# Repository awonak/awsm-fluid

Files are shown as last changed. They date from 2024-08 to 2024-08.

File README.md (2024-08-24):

# AWSM - Fluid

> [!NOTE]  
> This project is a work in progress and may contain errors.

3u 12hp Arduino based multi-purpose utility module. 

## Features

**Digital Inputs**

* 2 digital gate/trig inputs
* 2 buttons

**Analog Inputs**

* 4 slide potentiometers w/ addressable LEDs
* 4 CV inputs (-5v to 5v) w/ attenuator pots, summed with each slide pot.

**Analog Outputs**

* 2 PWM 0-10v outputs w/ LED indicator
* Each output paired with additional output which can be an inverted copy (-10v to 0v) or bipolar output (-10v to 10v).

## Concept

This module is meant to be a platform for creating unique utility module scripts using the given inputs and outputs. Some firmware examples are:

* CV controlable ADSR with gate / retrig inputs, envelope curves selected via button, envelope output with EOR/EOF output trigger.
* Clocked burst generator with high gate output during burst sequence.
* Dual LFO w/ shape and rate.
* Random cv generator w/ envelopes.

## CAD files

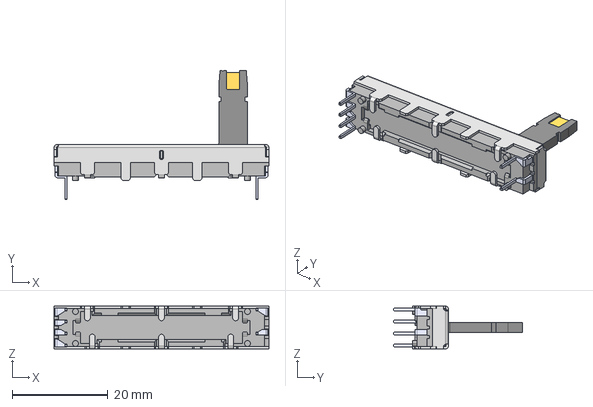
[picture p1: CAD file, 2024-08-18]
models/PTL20-15R0-103B1.step
45.0 x 27.0 x 9.00 mm

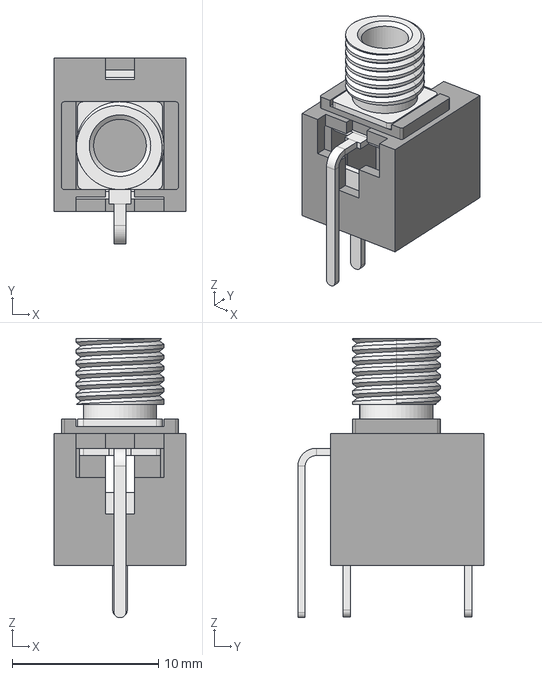
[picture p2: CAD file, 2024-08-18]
models/PJ398SM.step
9.00 x 12.7 x 19.1 mm

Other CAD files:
models/PTL30-15W1-103B1.step

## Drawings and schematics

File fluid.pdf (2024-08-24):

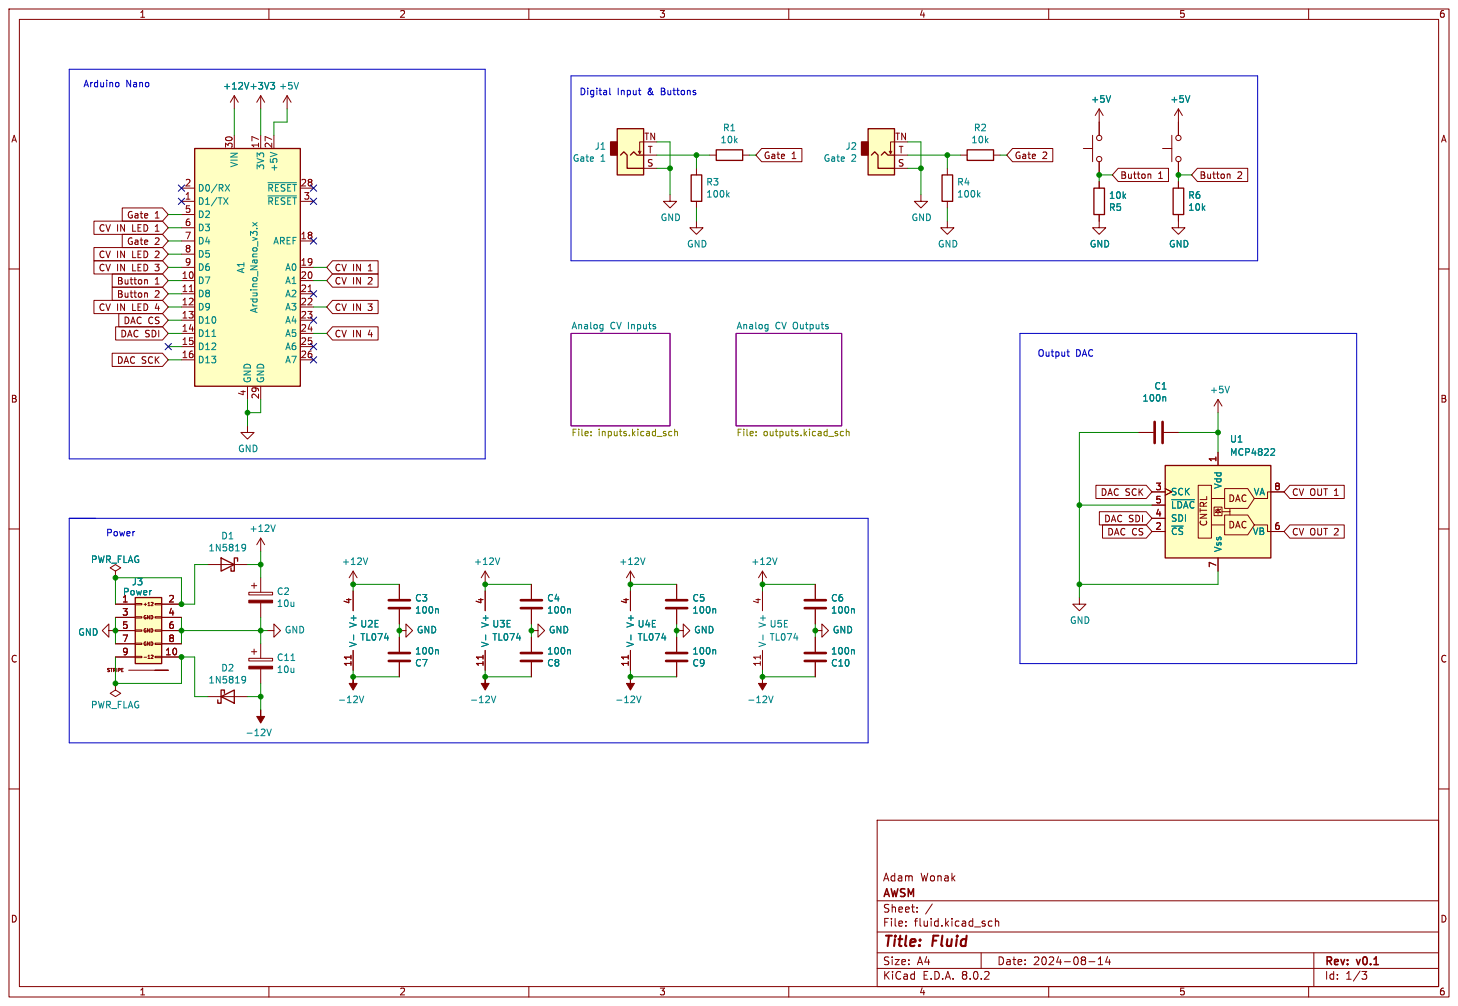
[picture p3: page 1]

1 ~{CS} 2 SCK 3 SDI 4 ~{LDAC} 5 VB 6 Vss 7 VA 8 GND

Analog CV Outputs File: outputs.kicad_sch GND

Analog CV Inputs File: inputs.kicad_sch

1 ~{CS} 2 SCK 3 SDI 4 ~{LDAC} 5 VB 6 Vss 7 VA 8 U1 MCP4822 C2

Adam Wonak
File: fluid.kicad_sch Sheet: / AWSM

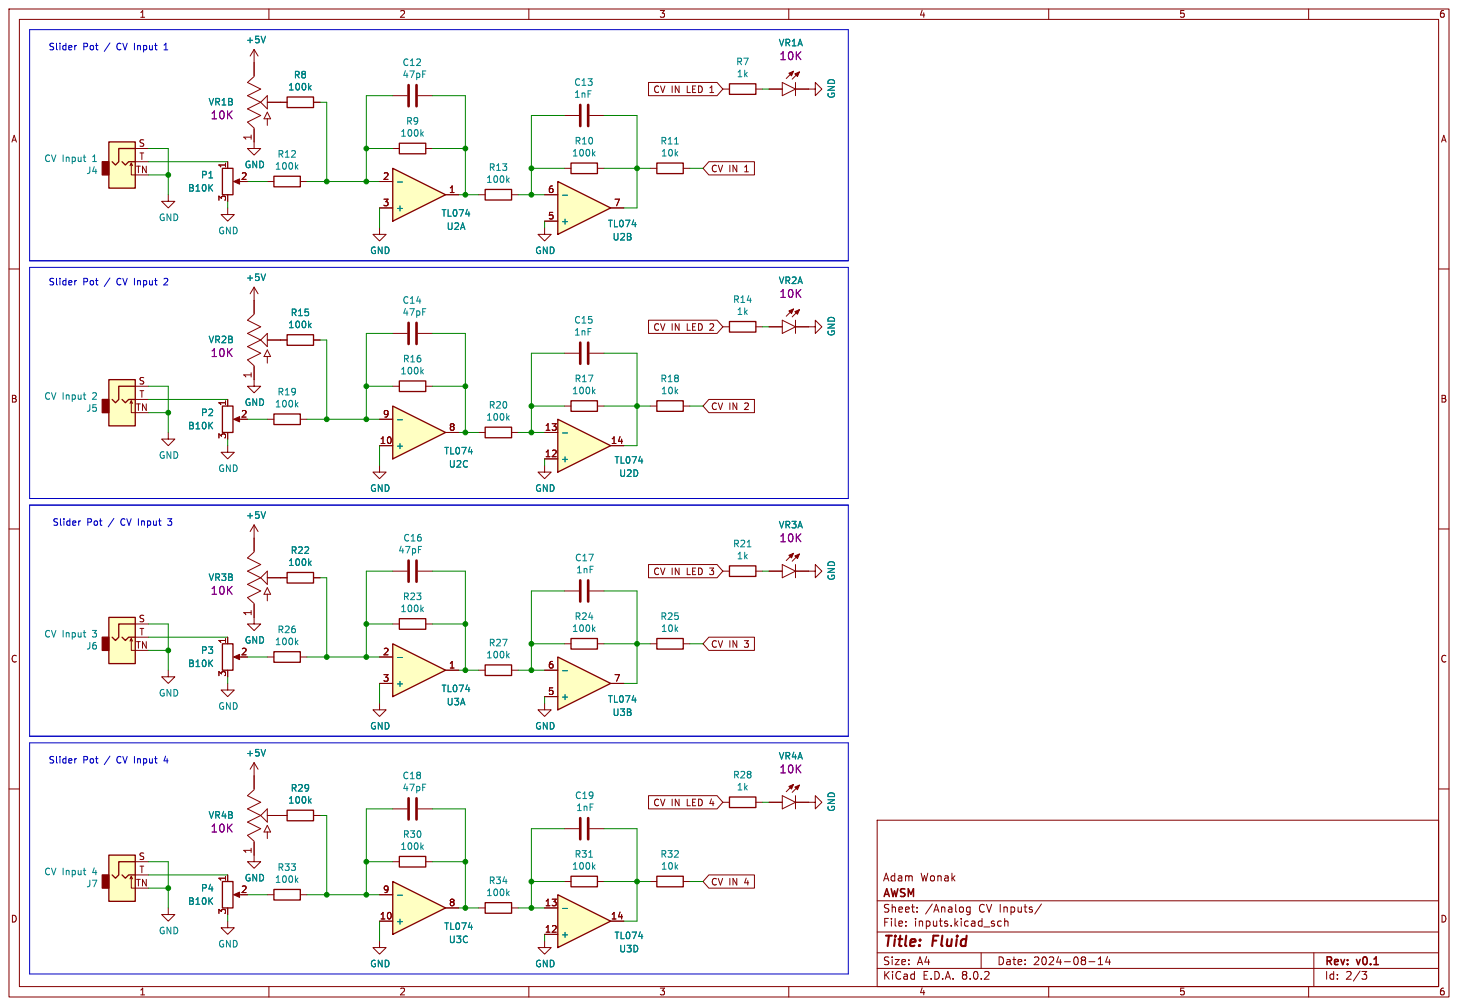
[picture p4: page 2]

CV IN LED 1 CV IN LED 3CV IN 3 CV IN LED 2CV IN 2 CV IN 1
TL074 GND GND ST

CV IN 4 CV IN LED 4 Slider Pot / CV Input 4

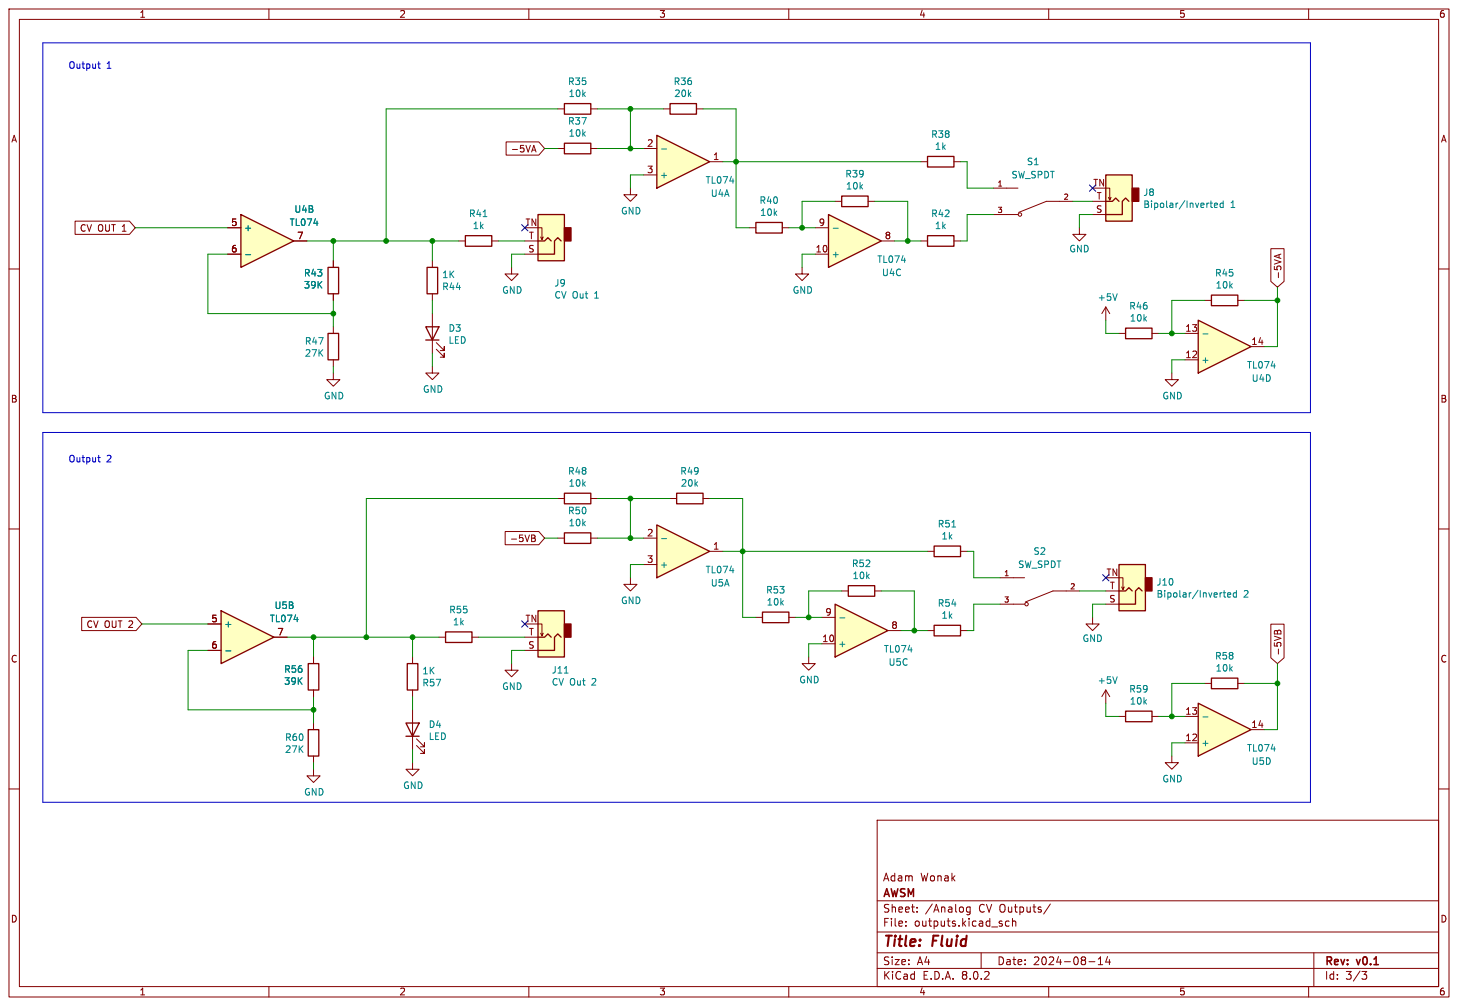
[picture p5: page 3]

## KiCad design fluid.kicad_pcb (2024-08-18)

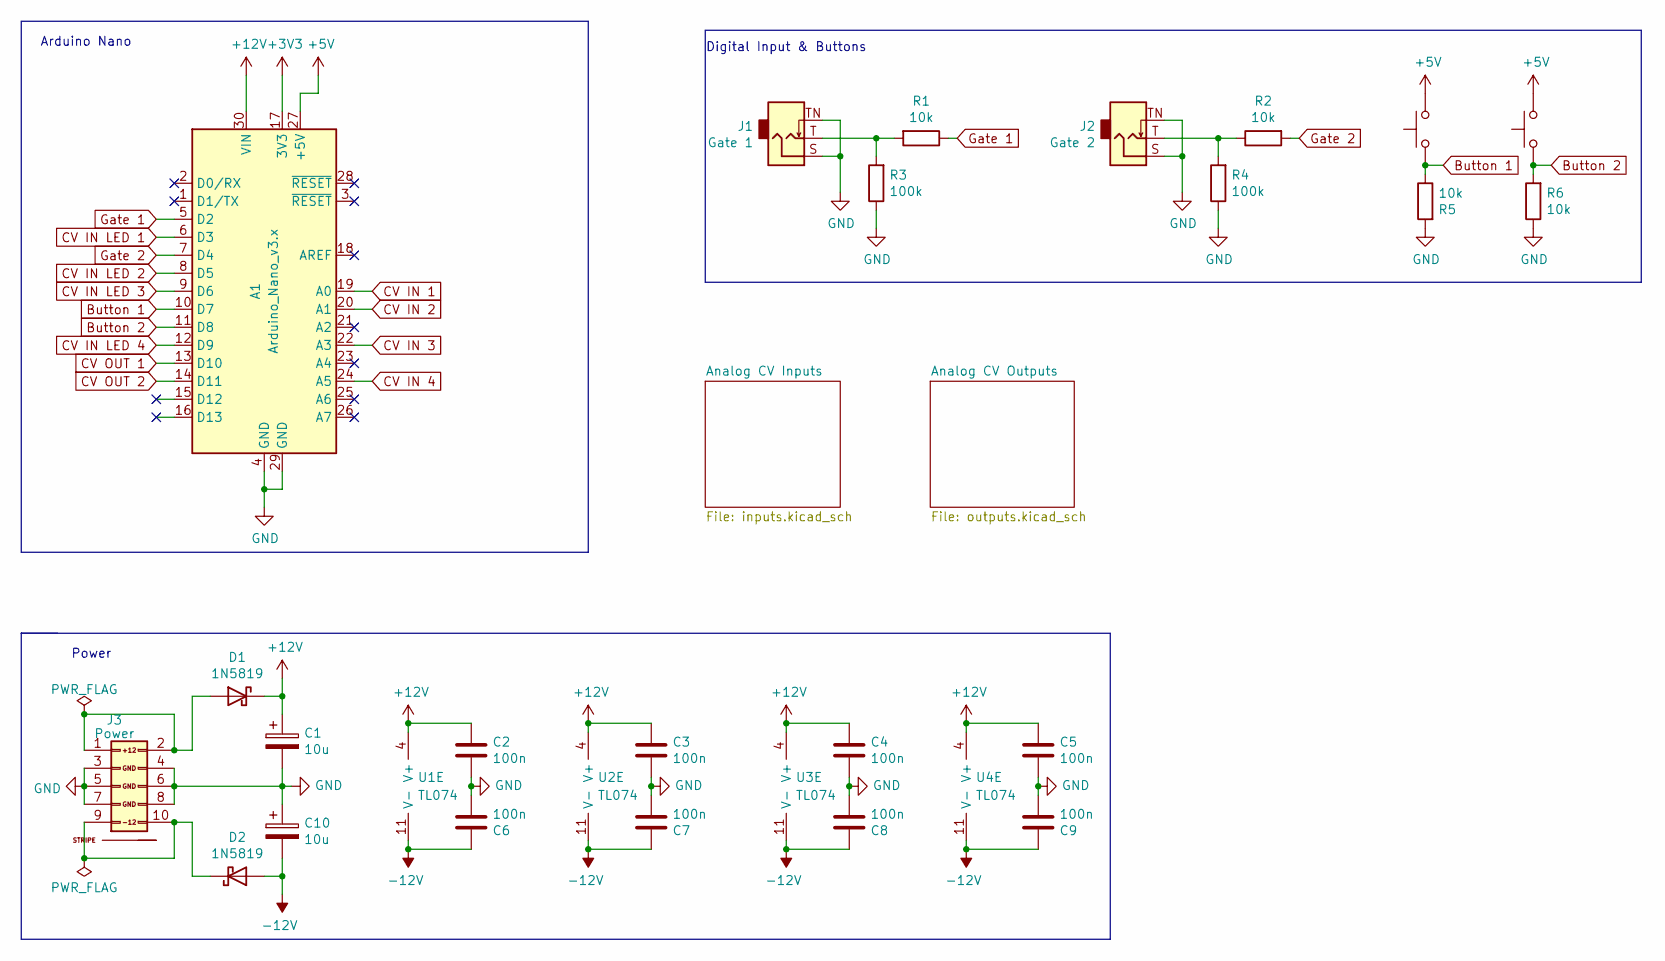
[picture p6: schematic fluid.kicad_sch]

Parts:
A1: Arduino_Nano_v3.x; Arduino_Nano
C1, C10: 10u; CP_EIA-3216-18_Kemet-A; LCSC C7171
C2, C3, C4, C5, C6, C7, C8, C9: 100n; C_0402_1005Metric; LCSC C1525
D1, D2: 1N5819; D_SOD-323; LCSC C191023
J1: Gate 1; Jack_3.5mm_QingPu_WQP-PJ398SM_Vertical_CircularHoles_3dModel
J2: Gate 2; Jack_3.5mm_QingPu_WQP-PJ398SM_Vertical_CircularHoles_3dModel
J3: Power; Pins_2x05_2.54mm_TH_EurorackPower
R1, R2, R5, R6: 10k; R_0402_1005Metric; LCSC C25744
R3, R4: 100k; R_0402_1005Metric; LCSC C25741
SW1, SW2: Button; SW_PUSH_6mm
U1, U2, U3, U4: TL074; SOIC-14_3.9x8.7mm_P1.27mm; LCSC C6963

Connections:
+3V3: A1.17 (3V3)
+5V: A1.27 (+5V), SW1.2, SW2.2; also elsewhere on the board
+12V: A1.30 (VIN), C1.1, C2.2, C3.2, C4.2, C5.2, D1.1 (K), U1.4 (V+), U2.4 (V+), U3.4 (V+), U4.4 (V+)
-12V: C6.2, C7.2, C8.2, C9.2, C10.2, D2.2 (A), U1.11 (V-), U2.11 (V-), U3.11 (V-), U4.11 (V-)
Button 1: A1.10 (D7), R5.1, SW1.1
Button 2: A1.11 (D8), R6.2, SW2.1
CV IN 1: A1.19 (A0); also elsewhere on the board
CV IN 2: A1.20 (A1); also elsewhere on the board
CV IN 3: A1.22 (A3); also elsewhere on the board
CV IN 4: A1.24 (A5); also elsewhere on the board
CV IN LED 1: A1.6 (D3); also elsewhere on the board
CV IN LED 2: A1.8 (D5); also elsewhere on the board
CV IN LED 3: A1.9 (D6); also elsewhere on the board
CV IN LED 4: A1.12 (D9); also elsewhere on the board
CV OUT 1: A1.13 (D10); also elsewhere on the board
CV OUT 2: A1.14 (D11); also elsewhere on the board
GND: A1.4 (GND), A1.29 (GND), C1.2, C2.1, C3.1, C4.1, C5.1, C6.1, C7.1, C8.1, C9.1, C10.1, J1.S, J1.TN, J2.S, J2.TN, J3.3 (GND), J3.4 (GND), J3.5 (GND), J3.6 (GND), J3.7 (GND), J3.8 (GND), R3.1, R4.1, R5.2, R6.1; also elsewhere on the board
Gate 1: A1.5 (D2), R1.1
Gate 2: A1.7 (D4), R2.2
unnamed: D1.2 (A), J3.1 (+12V), J3.2 (+12V)
unnamed: D2.1 (K), J3.9 (-12V), J3.10 (-12V)
unnamed: J1.T, R1.2, R3.2
unnamed: J2.T, R2.1, R4.2

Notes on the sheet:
Arduino Nano
Power
Digital Input & Buttons

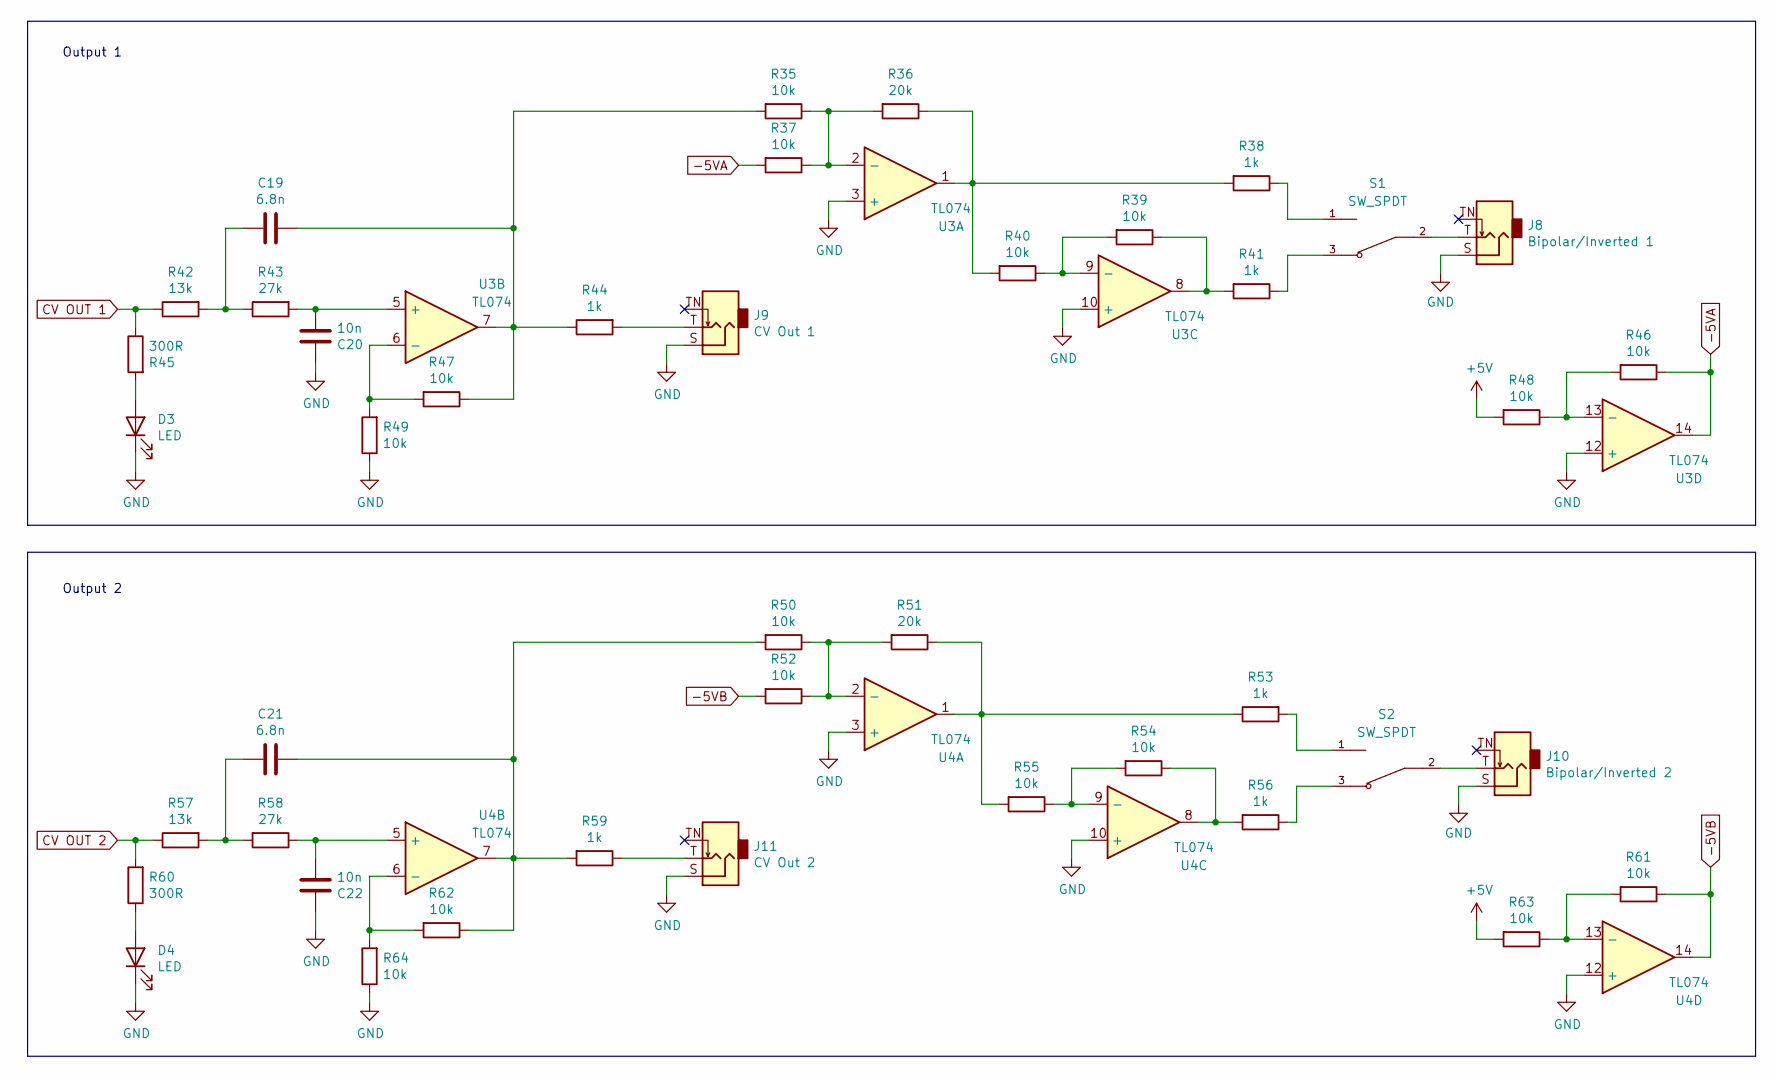
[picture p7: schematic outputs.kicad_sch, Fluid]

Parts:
C19, C21: 6.8n; C_0402_1005Metric; LCSC C1542
C20, C22: 10n; C_0402_1005Metric; LCSC C15195
D3, D4: LED; LED_D3.0mm
J8: Bipolar/Inverted 1; Jack_3.5mm_QingPu_WQP-PJ398SM_Vertical_CircularHoles_3dModel
J9: CV Out 1; Jack_3.5mm_QingPu_WQP-PJ398SM_Vertical_CircularHoles_3dModel
J10: Bipolar/Inverted 2; Jack_3.5mm_QingPu_WQP-PJ398SM_Vertical_CircularHoles_3dModel
J11: CV Out 2; Jack_3.5mm_QingPu_WQP-PJ398SM_Vertical_CircularHoles_3dModel
R35, R37, R39, R40, R46, R47, R48, R49, R50, R52, R54, R55, R61, R62, R63, R64: 10k; R_0402_1005Metric; LCSC C25744
R36, R51: 20k; R_0402_1005Metric; LCSC C25765
R38, R41, R44, R53, R56, R59: 1k; R_0402_1005Metric; LCSC C11702
R42, R57: 13k; R_0603_1608Metric; LCSC C22797
R43, R58: 27k; R_0402_1005Metric; LCSC C25771
R45, R60: 300R; R_0402_1005Metric; LCSC C25102
S1, S2: SW_SPDT; SW_2MS1T1B1M2QES
U3, U4: TL074; SOIC-14_3.9x8.7mm_P1.27mm; LCSC C6963

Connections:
+5V: R48.2, R63.2; also elsewhere on the board
-5VA: R37.2, R46.1, U3.14
-5VB: R52.2, R61.1, U4.14
CV OUT 1: R42.1, R45.1; also elsewhere on the board
CV OUT 2: R57.1, R60.2; also elsewhere on the board
GND: C20.2, C22.2, D3.1 (K), D4.1 (K), J8.S, J9.S, J10.S, J11.S, R49.1, R64.1, U3.3 (+), U3.10 (+), U3.12 (+), U4.3 (+), U4.10 (+), U4.12 (+); also elsewhere on the board
unnamed: C19.1, R35.2, R44.1, R47.1, U3.7
unnamed: C19.2, R42.2, R43.1
unnamed: C21.1, R50.2, R59.2, R62.1, U4.7
unnamed: C21.2, R57.2, R58.2
unnamed: D3.2 (A), R45.2
unnamed: D4.2 (A), R60.1
unnamed: J8.T, S1.2
unnamed: J9.T, R44.2
unnamed: J10.T, S2.2
unnamed: J11.T, R59.1
unnamed: R36.1, R38.2, R40.2, U3.1
unnamed: R38.1, S1.1
unnamed: R39.1, R41.2, U3.8
unnamed: R41.1, S1.3
unnamed: R51.1, R53.1, R55.2, U4.1
unnamed: R53.2, S2.1
unnamed: R54.1, R56.2, U4.8
unnamed: R56.1, S2.3
unnamed: R35.1, R36.2, R37.1, U3.2 (-)
unnamed: C20.1, R43.2, U3.5 (+)
unnamed: R47.2, R49.2, U3.6 (-)
unnamed: R39.2, R40.1, U3.9 (-)
unnamed: R46.2, R48.1, U3.13 (-)
unnamed: R50.1, R51.2, R52.1, U4.2 (-)
unnamed: C22.1, R58.1, U4.5 (+)
unnamed: R62.2, R64.2, U4.6 (-)
unnamed: R54.2, R55.1, U4.9 (-)
unnamed: R61.2, R63.1, U4.13 (-)

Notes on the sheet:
Output 2
Output 1

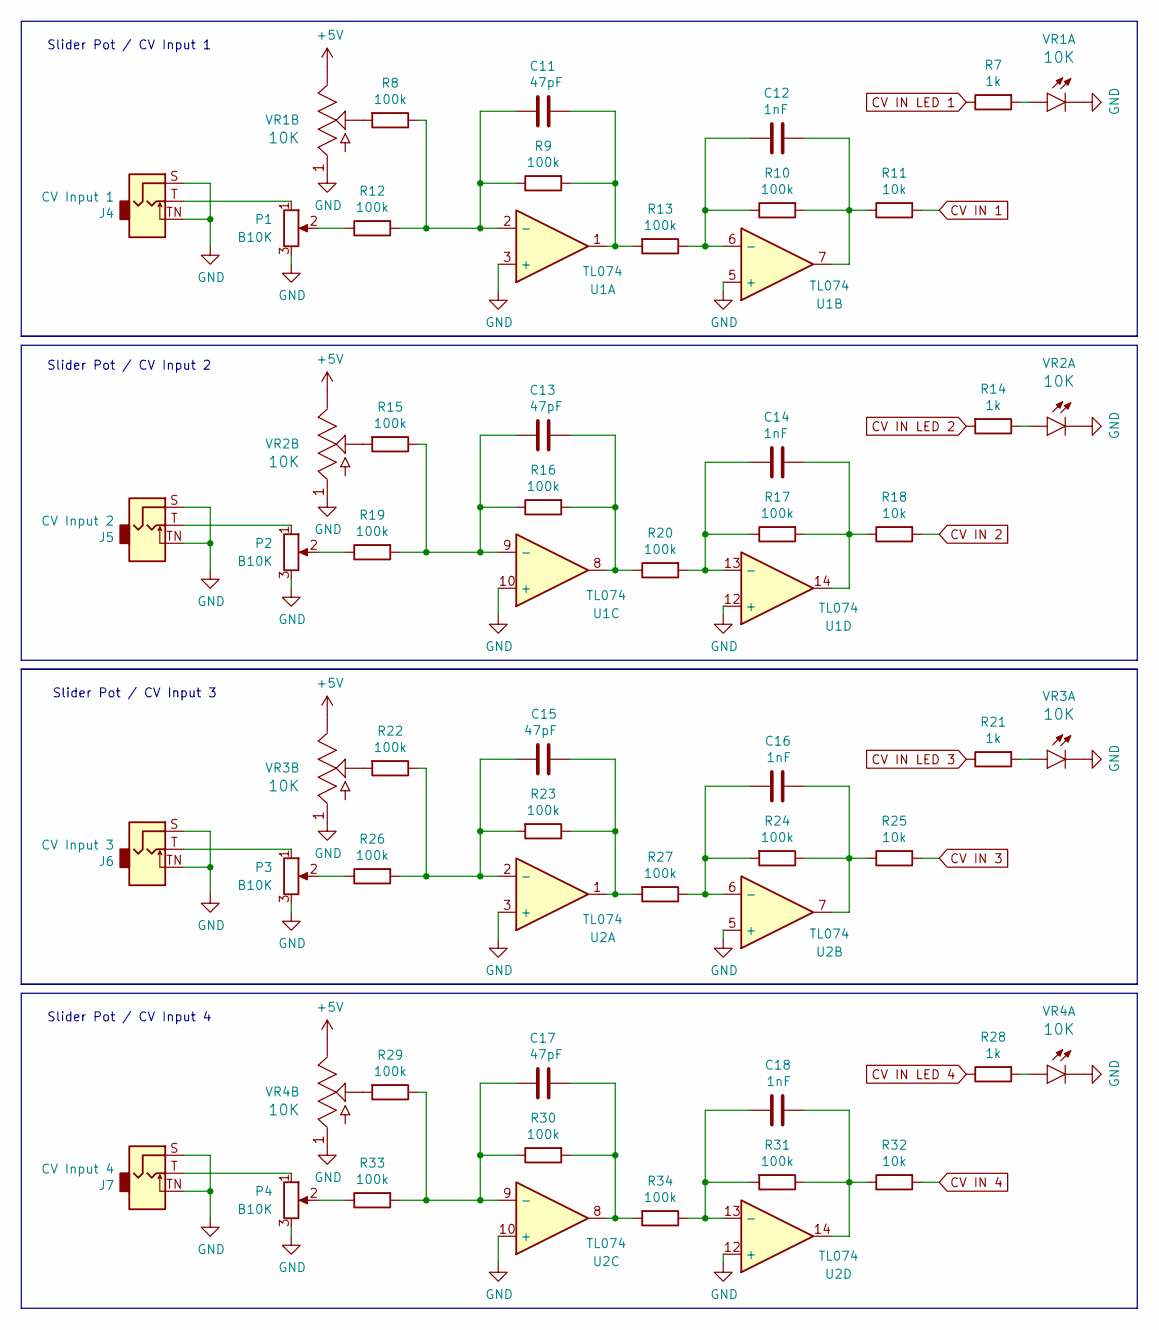
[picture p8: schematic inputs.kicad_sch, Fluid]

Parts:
C11, C13, C15, C17: 47pF; C_0402_1005Metric; LCSC C1567
C12, C14, C16, C18: 1nF; C_0402_1005Metric; LCSC C1523
J4: CV Input 1; Jack_3.5mm_QingPu_WQP-PJ398SM_Vertical_CircularHoles_3dModel
J5: CV Input 2; Jack_3.5mm_QingPu_WQP-PJ398SM_Vertical_CircularHoles_3dModel
J6: CV Input 3; Jack_3.5mm_QingPu_WQP-PJ398SM_Vertical_CircularHoles_3dModel
J7: CV Input 4; Jack_3.5mm_QingPu_WQP-PJ398SM_Vertical_CircularHoles_3dModel
P1, P2, P3, P4: B10K; Potentiometer_Alpha_RD901F-40-00D_Single_Vertical
R7, R14, R21, R28: 1k; R_0402_1005Metric; LCSC C11702
R8, R9, R10, R12, R13, R15, R16, R17, R19, R20, R22, R23, R24, R26, R27, R29, R30, R31, R33, R34: 100k; R_0402_1005Metric; LCSC C25741
R11, R18, R25, R32: 10k; R_0402_1005Metric; LCSC C25744
U1, U2: TL074; SOIC-14_3.9x8.7mm_P1.27mm; LCSC C6963
VR1, VR2, VR3, VR4: 10K; Pot_Slider_LED_20mm_RA2045F

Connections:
+5V: VR1.P3 (3), VR2.P3 (3), VR3.P3 (3), VR4.P3 (3); also elsewhere on the board
CV IN 1: R11.2; also elsewhere on the board
CV IN 2: R18.2; also elsewhere on the board
CV IN 3: R25.2; also elsewhere on the board
CV IN 4: R32.2; also elsewhere on the board
CV IN LED 1: R7.1; also elsewhere on the board
CV IN LED 2: R14.2; also elsewhere on the board
CV IN LED 3: R21.1; also elsewhere on the board
CV IN LED 4: R28.1; also elsewhere on the board
GND: J4.S, J4.TN, J5.S, J5.TN, J6.S, J6.TN, J7.S, J7.TN, P1.3, P2.3, P3.3, P4.3, U1.3 (+), U1.5 (+), U1.10 (+), U1.12 (+), U2.3 (+), U2.5 (+), U2.10 (+), U2.12 (+), VR1.LEDC (C), VR1.P1 (1), VR2.LEDC (C), VR2.P1 (1), VR3.LEDC (C), VR3.P1 (1), VR4.LEDC (C), VR4.P1 (1); also elsewhere on the board
unnamed: C11.1, R9.2, R13.2, U1.1
unnamed: C12.1, R10.2, R11.1, U1.7
unnamed: C13.1, R16.2, R20.1, U1.8
unnamed: C14.1, R17.2, R18.1, U1.14
unnamed: C15.2, R23.1, R27.2, U2.1
unnamed: C16.2, R24.1, R25.1, U2.7
unnamed: C17.1, R30.2, R34.2, U2.8
unnamed: C18.2, R31.1, R32.1, U2.14
unnamed: J4.T, P1.1
unnamed: J5.T, P2.1
unnamed: J6.T, P3.1
unnamed: J7.T, P4.1
unnamed: P1.2, R12.1
unnamed: P2.2, R19.1
unnamed: P3.2, R26.1
unnamed: P4.2, R33.1
unnamed: C11.2, R8.1, R9.1, R12.2, U1.2 (-)
unnamed: C12.2, R10.1, R13.1, U1.6 (-)
unnamed: C13.2, R15.1, R16.1, R19.2, U1.9 (-)
unnamed: C14.2, R17.1, R20.2, U1.13 (-)
unnamed: C15.1, R22.1, R23.2, R26.2, U2.2 (-)
unnamed: C16.1, R24.2, R27.1, U2.6 (-)
unnamed: C17.2, R29.1, R30.1, R33.2, U2.9 (-)
unnamed: C18.1, R31.2, R34.1, U2.13 (-)
unnamed: R7.2, VR1.LEDA (A)
unnamed: R8.2, VR1.P2 (2)
unnamed: R14.1, VR2.LEDA (A)
unnamed: R15.2, VR2.P2 (2)
unnamed: R21.2, VR3.LEDA (A)
unnamed: R22.2, VR3.P2 (2)
unnamed: R28.2, VR4.LEDA (A)
unnamed: R29.2, VR4.P2 (2)

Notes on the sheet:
Slider Pot / CV Input 2
Slider Pot / CV Input 4
Slider Pot / CV Input 1
Slider Pot / CV Input 3

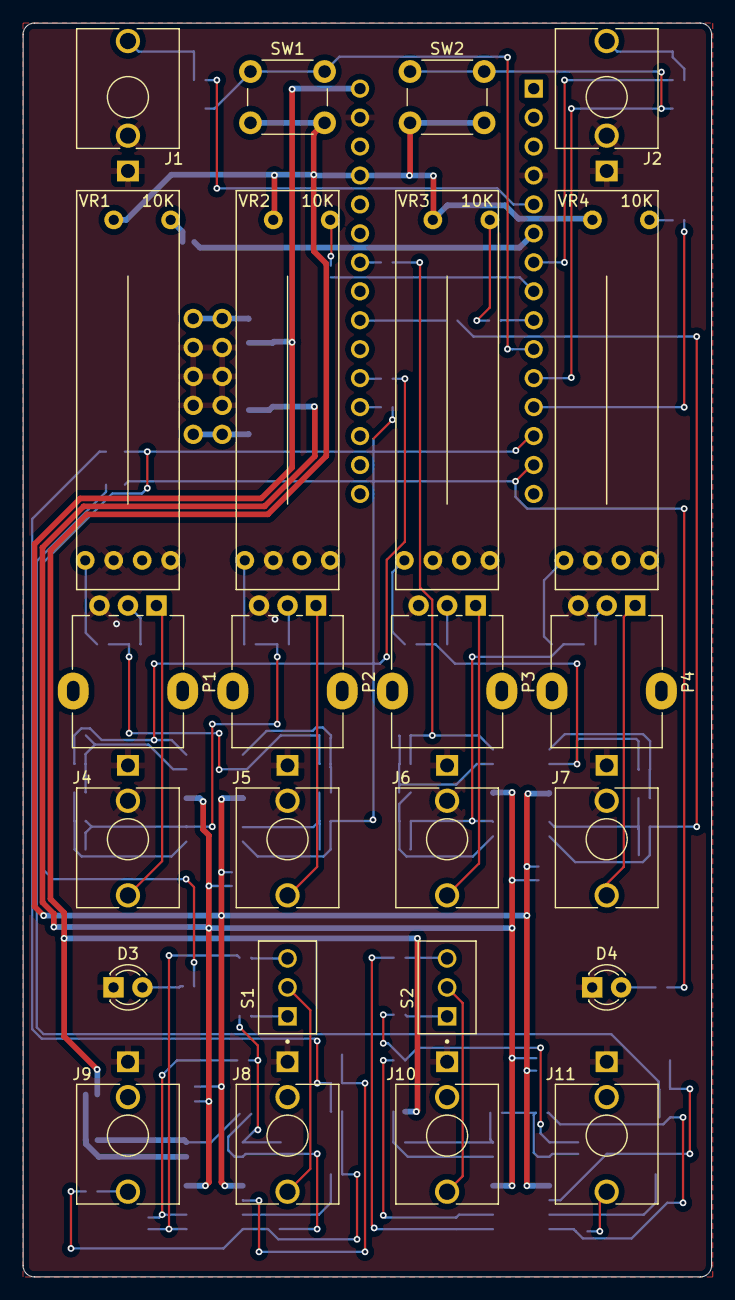
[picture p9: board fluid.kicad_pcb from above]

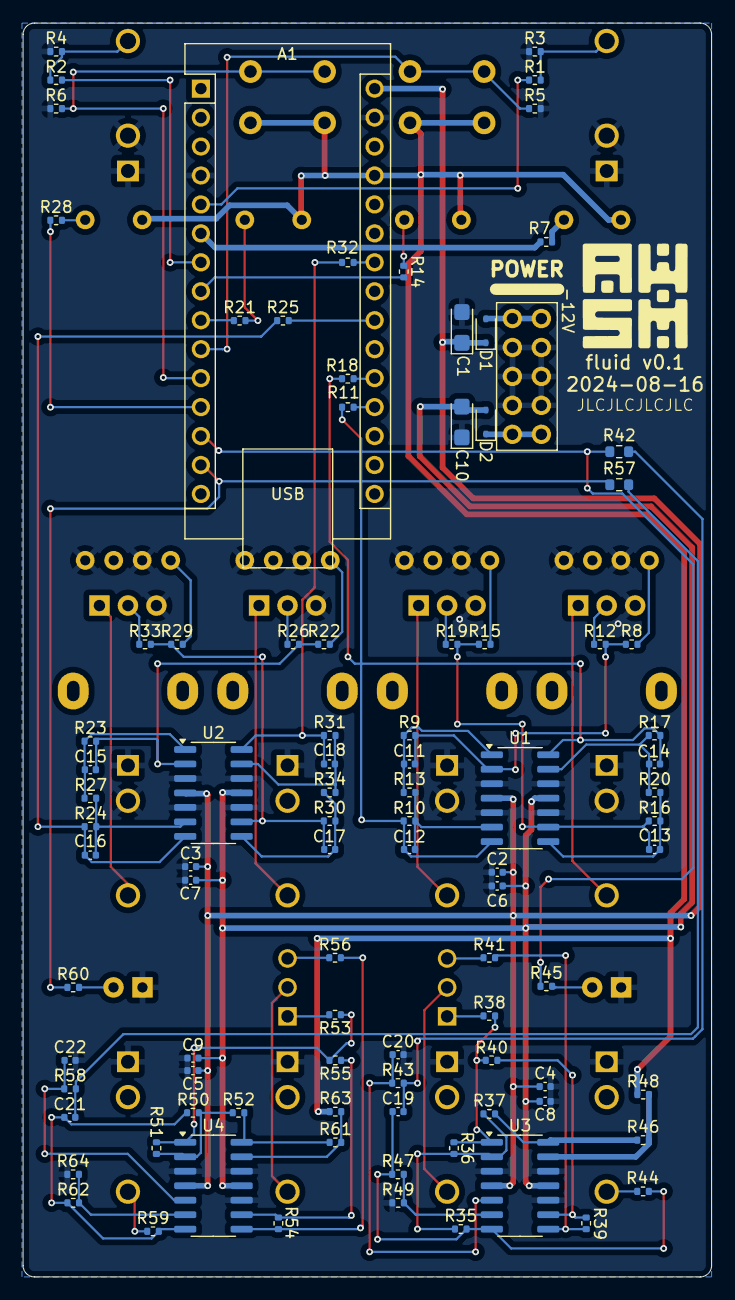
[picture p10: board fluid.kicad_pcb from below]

Board: 2 copper layers, 60.4 x 110.0 mm, 118 parts (94 on the bottom side), 84 nets.

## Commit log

2024-08-18 fixed absolute symbol reference. rounded corners of pcb.
    [fluid.kicad_pcb]
2024-08-24 Reintroduce the DAC with gain boost from 4.096v to 9.99v. Refactor output LED, increase LED resistor value.
    [fluid.kicad_sch, inputs.kicad_sch, outputs.kicad_sch]
2024-08-24 update schematic
2024-08-24 reorder annotations, replot pdf schematic
    [fluid.kicad_sch, inputs.kicad_sch, outputs.kicad_sch]
